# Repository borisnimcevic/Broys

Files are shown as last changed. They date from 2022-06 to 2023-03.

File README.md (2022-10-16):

# Watchular (ESP32-C3 based modular watch)

### Name origin:
* watch + modular

### Bill Of Materials
|Component  |Quantity |Link |
|----- |----- |-----  |
|ESP32-C3 |1 |[digikey](https://www.digikey.se/en/products/detail/espressif-systems/ESP32-C3-MINI-1-N4-A/15817506) |
|or with embedded flash (ESP32-C3FN4) |1 |[digikey](https://www.digikey.se/en/products/detail/espressif-systems/ESP32-C3FH4/14115592) |
|Battery charger|1 |[digikey](https://www.digikey.se/en/products/detail/microchip-technology/MCP73832T-2DCI-OT/1223150) |
|Battery connector|1 |[digikey](https://www.digikey.se/en/products/detail/w%C3%BCrth-elektronik/665102131822/5047757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) |
|Button|2 |[digikey](https://www.digikey.se/en/products/detail/e-switch/TL3301AF260QG/378995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) |
|Ceramic antenna (chip antenna)|1 |[digikey](https://www.digikey.se/en/products/detail/johanson-technology-inc/2450AT18A100E/1560676) |
|Ceramic capacitor 100nF 0402 |4 |[digikey](https://www.digikey.se/en/products/detail/taiyo-yuden/EMK105B7104KV-F/1004039) |
|Ceramic capacitor 1pF 0402 |1 |[digikey](https://www.digikey.se/en/products/detail/walsin-technology-corporation/0402N1R0B500CT/9354767) |
|Ceramic capacitor 1uF 0603 |2 |[digikey](https://www.digikey.se/en/products/detail/taiyo-yuden/EMK107BJ105KA-T/930603) |
|Ceramic capacitor 2.2uF 0603 |2 |[digikey](https://www.digikey.se/en/products/detail/taiyo-yuden/EMK107BJ225KA-T/1004018) |
|Ceramic capacitor 4.7uF 0402 |1 |[digikey](https://www.digikey.se/en/products/detail/murata-electronics/GRT155R60J475ME13J/13904800) |
|Ceramic capacitor 4.7uF 0603 |2 |[digikey](https://www.digikey.se/en/products/detail/taiyo-yuden/JMK107BJ475KA-T/1169922) |
|Ceramic capacitor 8pF 0402 |2 |[digikey](https://www.digikey.se/en/products/detail/taiyo-yuden/UMK105CH080DVHF/6563655) |
|Ceramic inductor 2.7nH |1 |[digikey](https://www.digikey.se/en/products/detail/johanson-technology-inc/L-07C2N7SV6T/1830166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) |
|Ceramic inductor 3.9nH |1 |[digikey](https://www.digikey.se/en/products/detail/johanson-technology-inc/L-07C3N9SV6T/1915227) |
|Crystal 16MHz|1 |[digikey](https://www.digikey.se/en/products/detail/txc-corporation/8Y-16-000MAHQ-T/6130681) |
|FLASH 4MBIT |1 |[digikey](https://www.digikey.se/en/products/detail/winbond-electronics/W25Q16JVSSIM/12143335) |
|LDO 3.3V 600mA|1 |[digikey](https://www.digikey.se/en/products/detail/diodes-incorporated/AP7366-33W5-7/9867322) |
|LED Orange 0402|1 |[digikey](https://www.digikey.se/en/products/detail/sunled/XZMOK68W-2/4902071) |
|LED Red 0603|30 |[digikey](https://www.digikey.se/en/products/detail/liteon/LTST-C191KRKT/386837) |
|Male Header 16 positions (1 row)|2 |[digikey](https://www.digikey.se/en/products/detail/adam-tech/PH1-16-UA/9830344) |
|N-channel MOSFET|4 |[digikey](https://www.digikey.se/en/products/detail/toshiba-semiconductor-and-storage/T2N7002AK-LM/5298028) |
|P-channel MOSFET|1 |[digikey](https://www.digikey.se/en/products/detail/diodes-incorporated/DMP2004K-7/1774201) |
|Resistor 0 ohm 0402 |1 |[digikey](https://www.digikey.se/en/products/detail/yageo/RC0402JR-070RP/4935294) |
|Resistor 100k 0402 |1 |[digikey](https://www.digikey.se/en/products/detail/yageo/RC0402JR-07100KL/726416) |
|Resistor 10k 0402 |4 |[digikey](https://www.digikey.se/en/products/detail/yageo/RC0402JR-0710KL/726418) |
|Resistor 1k 0402 |5 |[digikey](https://www.digikey.se/en/products/detail/delta-electronics-cyntec/PFR05S-102-JNH/9761533) |
|Resistor 2k 0402 |1 |[digikey](https://www.digikey.se/en/products/detail/yageo/RC0402JR-072KL/726434) |
|Resistor 5.1k 1% 0402 |2 |[digikey](https://www.digikey.se/en/products/detail/yageo/RC0402FR-135K1L/14286364) |
|Resistor 560 0402 |9 |[digikey](https://www.digikey.se/en/products/detail/yageo/RC0402JR-07560RL/726492) |
|Schottky|1 |[digikey](https://www.digikey.se/en/products/detail/smc-diode-solutions/DSS16U/8341861) |
|USB-C|1 |[digikey](https://www.digikey.se/en/products/detail/gct/USB4105-GF-A/11198441) |
|ESD-protector|1 |[digikey](https://www.digikey.se/en/products/detail/smc-diode-solutions/SR05/10820120) |

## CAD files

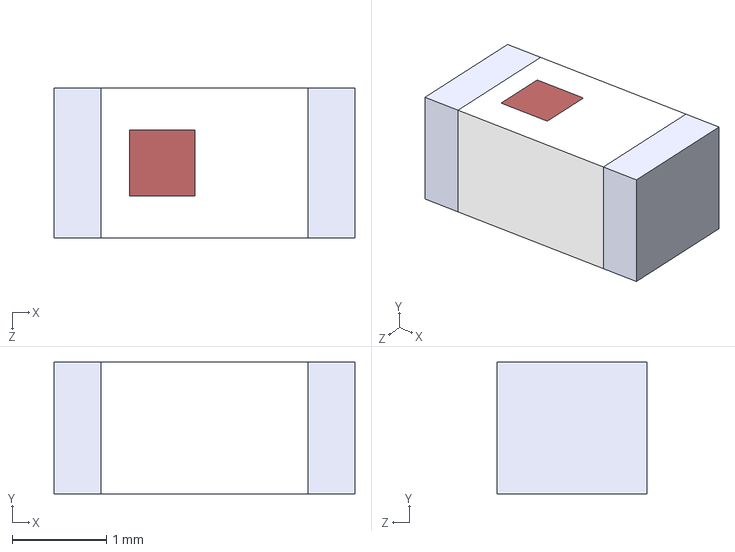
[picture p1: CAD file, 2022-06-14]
hardware/kicad-parts/ANT-2450AT18A100E/2450AT18A100E.step
3.20 x 1.40 x 1.60 mm

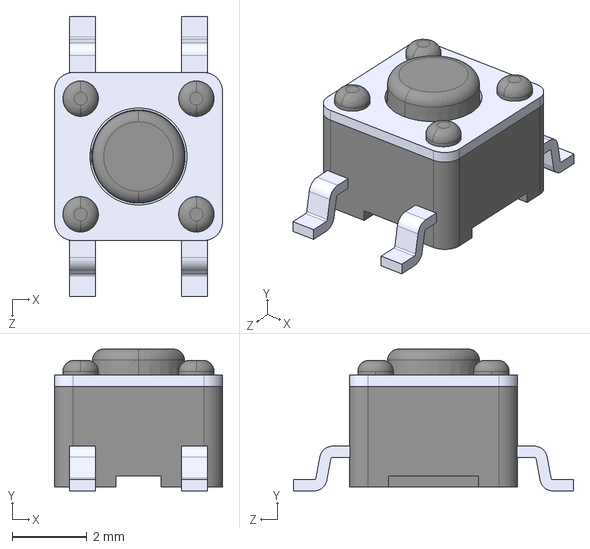
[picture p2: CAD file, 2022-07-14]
hardware/kicad-parts/button_TL3305AF260QG/TL3305AF260QG.step
4.50 x 3.80 x 7.50 mm

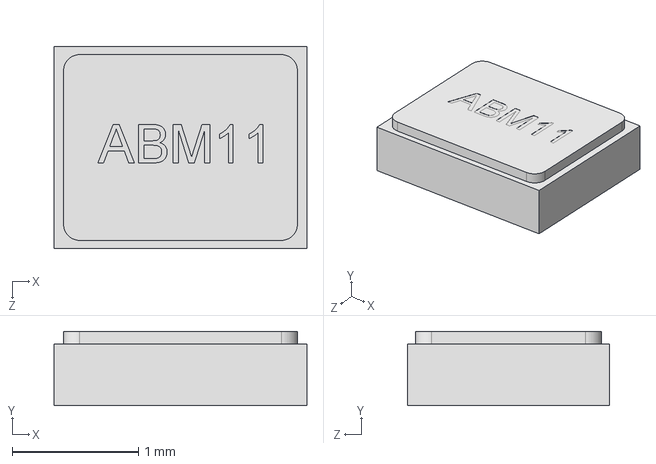
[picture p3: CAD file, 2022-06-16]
hardware/kicad-parts/Crystal/ABM1116.000MHZ-B7GT.STEP
2.01 x 0.59 x 1.60 mm

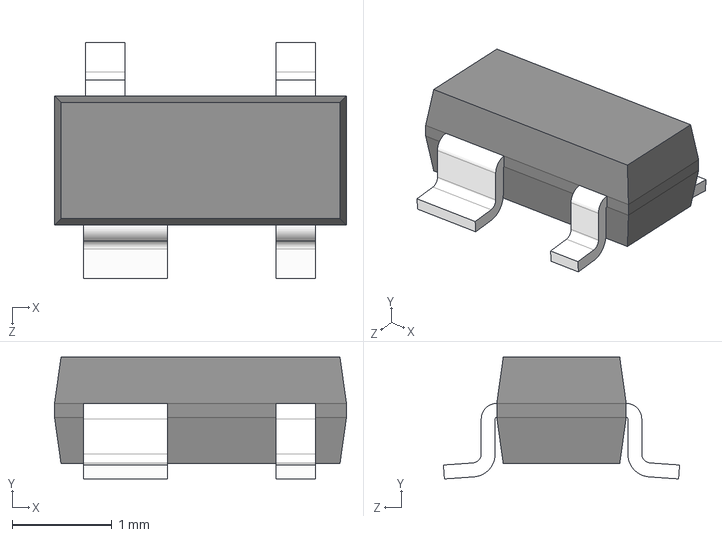
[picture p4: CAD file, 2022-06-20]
hardware/kicad-parts/ESD_protection-SR05/SR05.step
2.92 x 1.22 x 2.36 mm

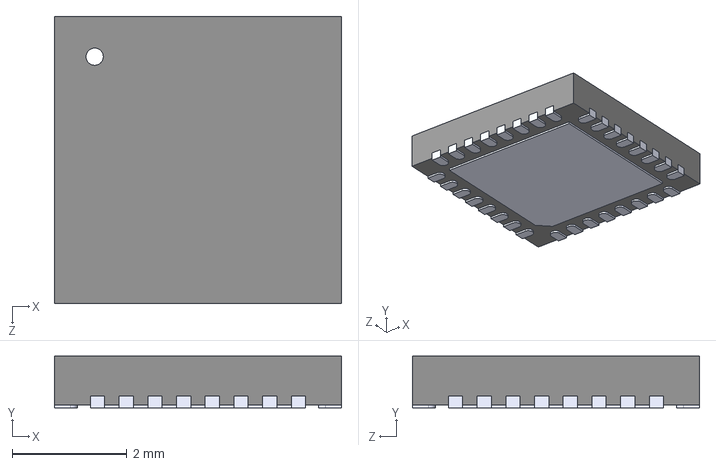
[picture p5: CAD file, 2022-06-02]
hardware/kicad-parts/ESP32-C3/ESP32-C3FH4.step
5.00 x 0.9 x 5.00 mm

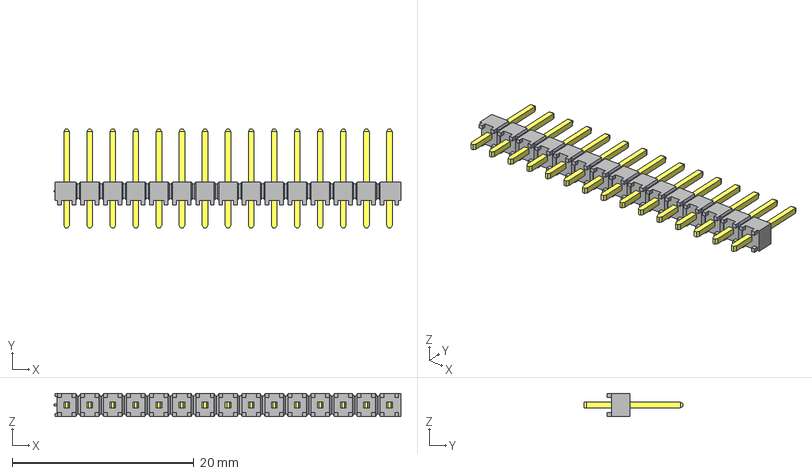
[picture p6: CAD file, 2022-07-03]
hardware/kicad-parts/header-TSW-115-07-H-S/TSW-115-07-H-S.step
38.2 x 10.9 x 2.54 mm
T-1S6-07-TSW-1-07-15-S
TSW-115-07-H-S_body

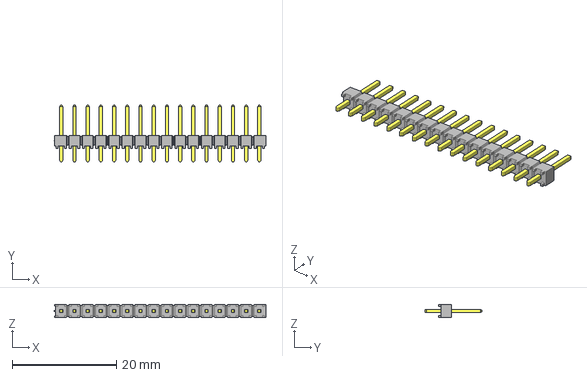
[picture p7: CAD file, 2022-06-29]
hardware/kicad-parts/header-TSW-116-07-H-S/TSW-116-07-H-S.step
40.8 x 10.9 x 2.54 mm
T-1S6-07-TSW-1-07-16-S
TSW-116-07-H-S_body

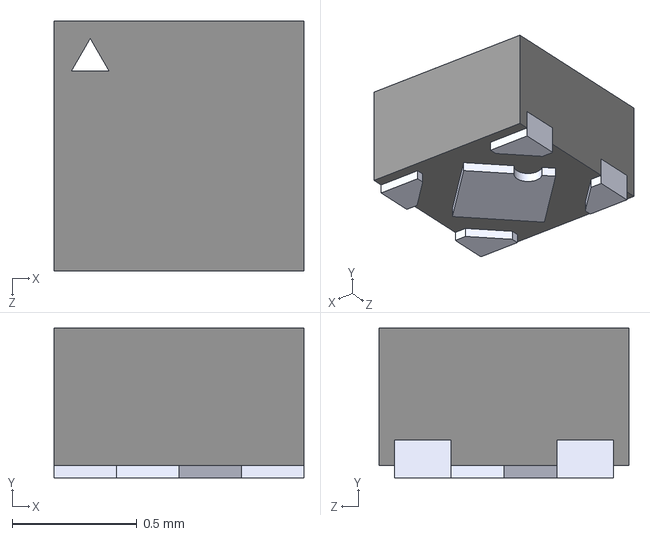
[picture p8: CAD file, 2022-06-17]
hardware/kicad-parts/LDO-MIC5524-3-3YMT-TZ/MIC5524-3.3YMT-TZ.step
1.00 x 0.6 x 1.00 mm

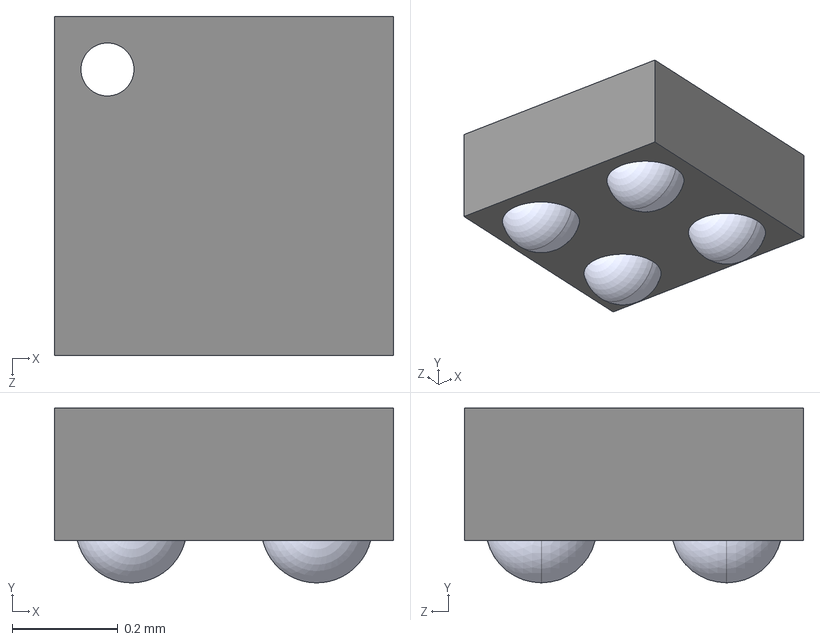
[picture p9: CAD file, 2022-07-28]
hardware/kicad-parts/LDO-NCP161AFCT330T2G/NCP161BFCT330T2G.step
0.64 x 0.33 x 0.64 mm

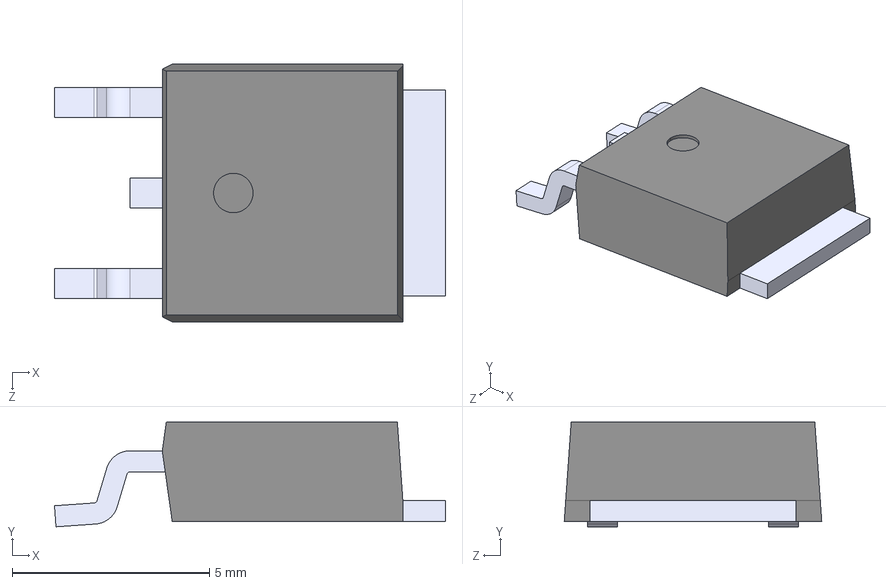
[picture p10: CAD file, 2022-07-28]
hardware/kicad-parts/LDO-UA78M33CKVURG3/UA78M33CKVURG3.step
9.90 x 2.65 x 6.52 mm

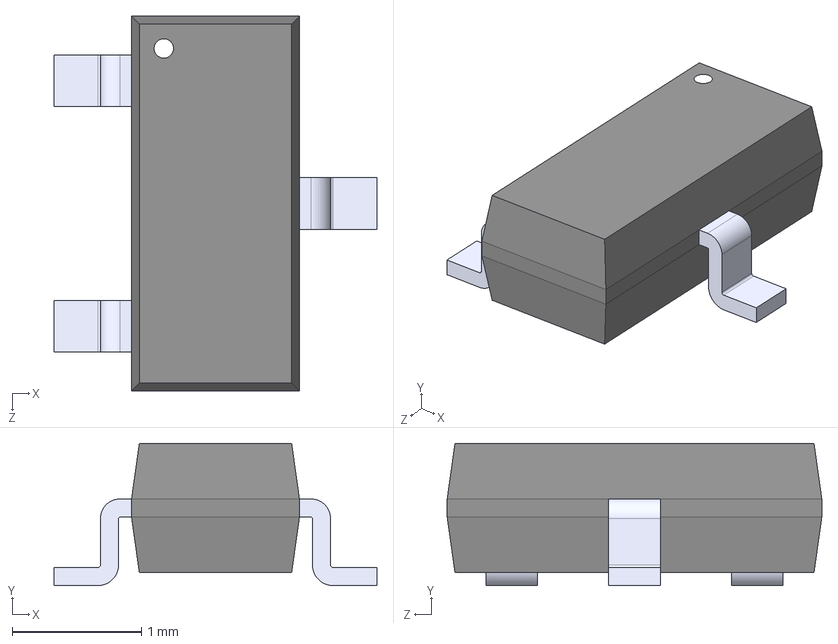
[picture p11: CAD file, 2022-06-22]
hardware/kicad-parts/MOSFET-BSS123/BSS123.step
2.50 x 1.10 x 2.90 mm

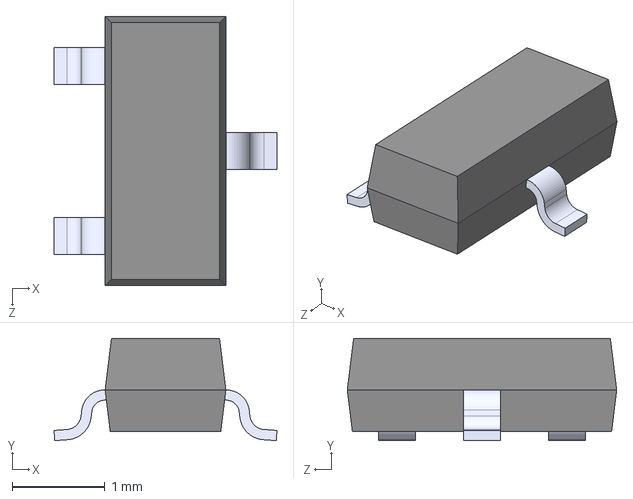
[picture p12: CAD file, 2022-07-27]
hardware/kicad-parts/N_MOSFET_STO91P240X105/SOT91P240X105-3N.step
2.40 x 1.10 x 2.90 mm

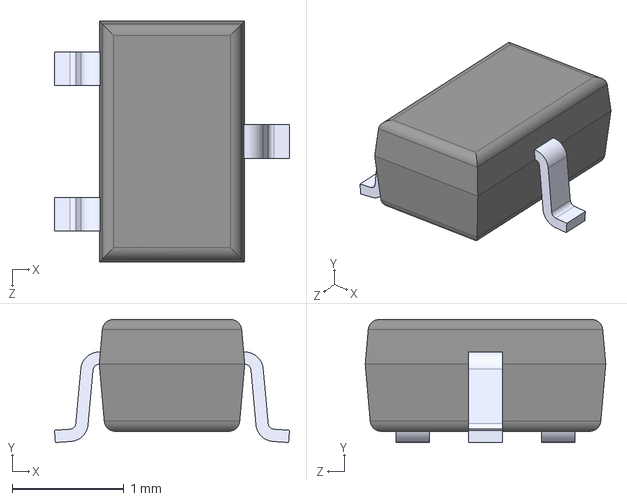
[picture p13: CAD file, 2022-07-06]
hardware/kicad-parts/P_MOSFET-DMG1013UW/DMG1013UW-7.step
2.10 x 1.10 x 2.15 mm

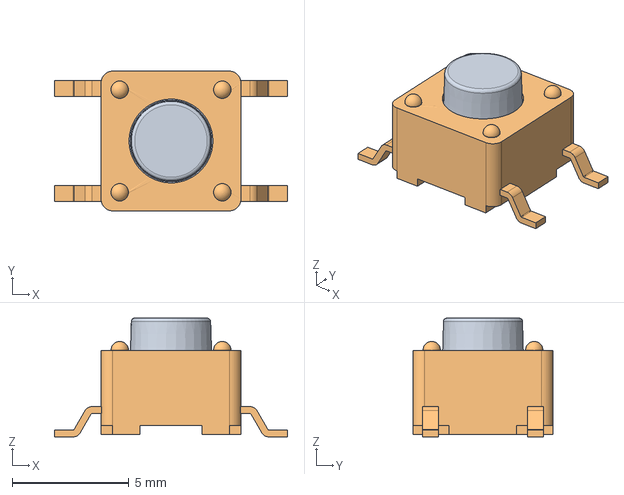
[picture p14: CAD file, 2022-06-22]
hardware/kicad-parts/switch-TL3301AF260QG/TL3301AF260QG.step
10.0 x 6.00 x 5.10 mm

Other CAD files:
hardware/kicad-parts/USBC-USB4105-GF-A/USB4105-GF-A.step
hardware/kicad-parts/battery_charger-MCP73832T/MCP73832T-2DCI_OT.step
hardware/kicad-parts/battery_connector-665102131822/665102131822.step

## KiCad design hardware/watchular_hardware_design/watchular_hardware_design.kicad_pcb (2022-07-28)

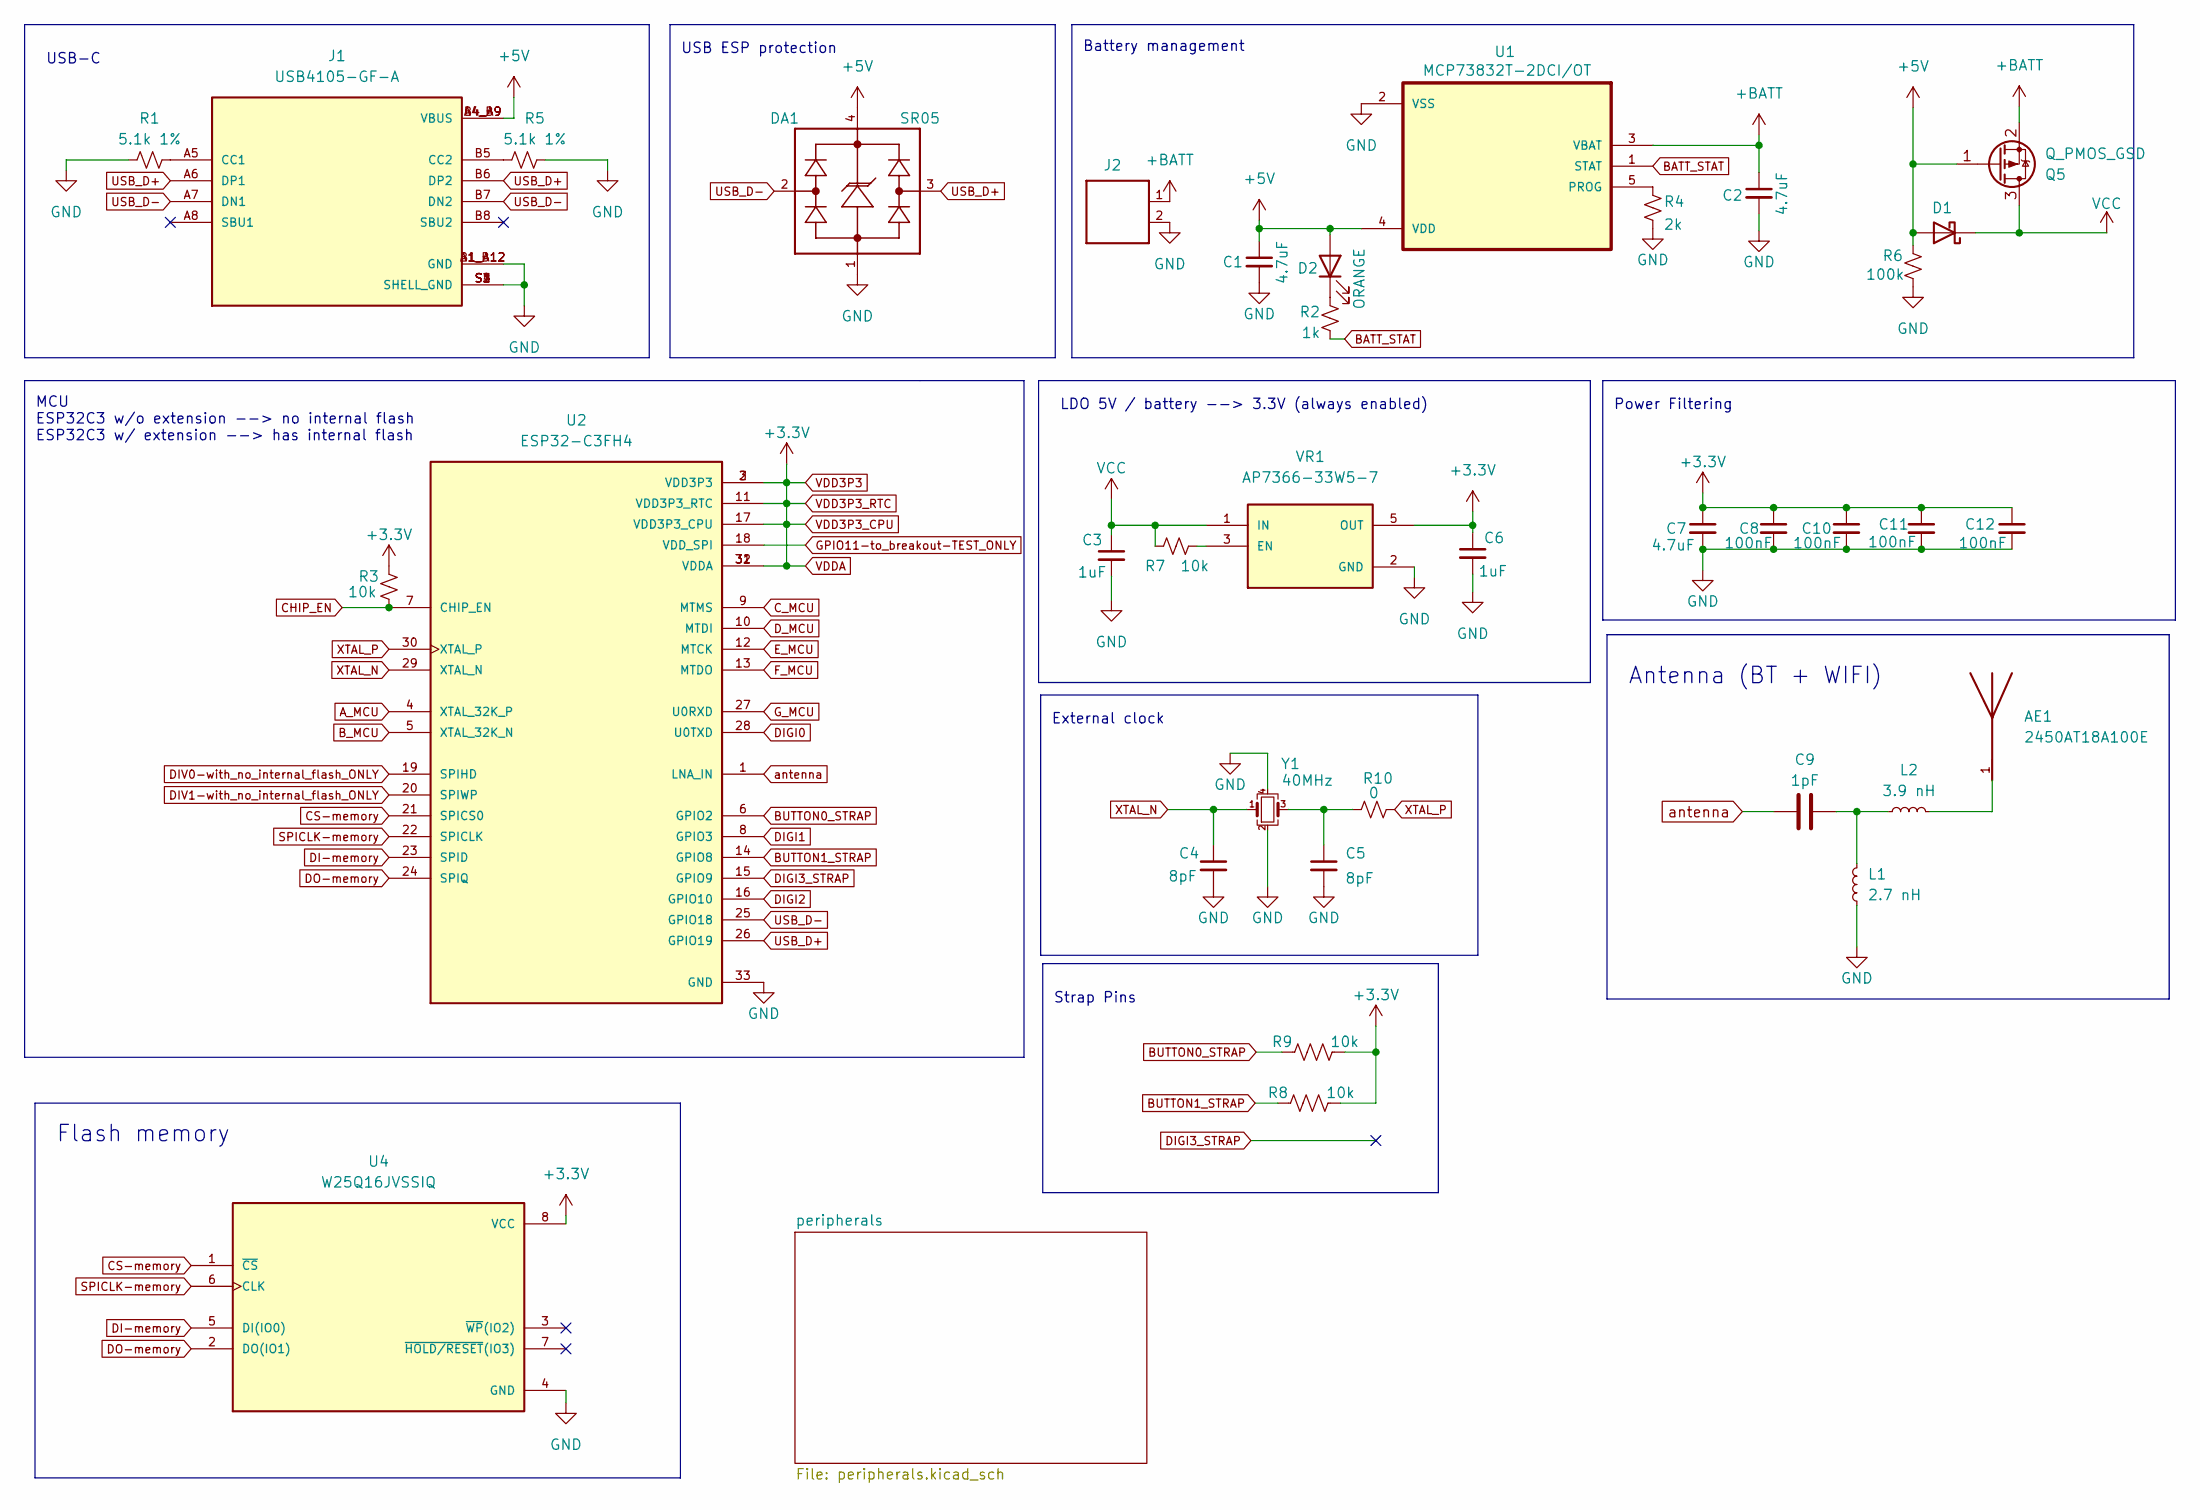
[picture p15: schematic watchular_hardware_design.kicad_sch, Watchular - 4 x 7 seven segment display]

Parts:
AE1: 2450AT18A100E; ANTC3216X140N; PARTREV 1.3
C1, C2: 4.7uF; C_0603_1608Metric_Pad1.08x0.95mm_HandSolder
C3, C6: 1uF; C_0603_1608Metric_Pad1.08x0.95mm_HandSolder
C4, C5: 8pF; C_0402_1005Metric_Pad0.74x0.62mm_HandSolder
C7: 4.7uF; L_0402_1005Metric
C8, C10, C11, C12: 100nF; L_0402_1005Metric
C9: 1pF; C_0402_1005Metric
D1: D_Schottky; D_SOD-123F
D2: ORANGE; LED_0402_1005Metric_Pad0.77x0.64mm_HandSolder
DA1: SR05; SOT143
J1: USB4105-GF-A; GCT_USB4105-GF-A; PARTREV A3
J2: 665102131822
L1: 2.7 nH; L_0402_1005Metric
L2: 3.9 nH; L_0402_1005Metric
Q5: Q_PMOS_GSD; SOT91P240X105-3N
R1, R5: 5.1k 1%; R_0402_1005Metric_Pad0.72x0.64mm_HandSolder
R2: 1k; R_0402_1005Metric_Pad0.72x0.64mm_HandSolder
R3, R7, R8, R9: 10k; R_0402_1005Metric_Pad0.72x0.64mm_HandSolder
R4: 2k; R_0402_1005Metric_Pad0.72x0.64mm_HandSolder
R6: 100k; R_0402_1005Metric_Pad0.72x0.64mm_HandSolder
R10: 0; R_0402_1005Metric_Pad0.72x0.64mm_HandSolder
U1: MCP73832T-2DCI/OT; SOT95P280X145-5N
U2: ESP32-C3FH4; QFN50P500X500X90-33N; PARTREV V1.0
U4: W25Q16JVSSIQ; SOIC127P790X216-8N
VR1: AP7366-33W5-7; SOT95P285X140-5N; PARTREV 1-2
Y1: 40MHz; Crystal_SMD_2016-4Pin_2.0x1.6mm

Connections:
+5V: C1.1, D1.2 (A), D2.2 (A), DA1.4, J1.A4_B9 (VBUS), J1.B4_A9 (VBUS), Q5.1 (G), R6.1, U1.4 (VDD); also elsewhere on the board
+BATT: C2.1, J2.1, Q5.2 (S), U1.3 (VBAT); also elsewhere on the board
A_MCU: U2.4 (XTAL_32K_P); also elsewhere on the board
BATT_STAT: R2.2, U1.1 (STAT)
BUTTON0_STRAP: R9.1, U2.6 (GPIO2); also elsewhere on the board
BUTTON1_STRAP: R8.1, U2.14 (GPIO8); also elsewhere on the board
B_MCU: U2.5 (XTAL_32K_N); also elsewhere on the board
CHIP_EN: R3.2, U2.7 (CHIP_EN); also elsewhere on the board
CS-memory: U2.21 (SPICS0), U4.1 (~CS); also elsewhere on the board
C_MCU: U2.9 (MTMS); also elsewhere on the board
DI-memory: U2.23 (SPID), U4.5 (DI(IO0)); also elsewhere on the board
DIGI0: U2.28 (U0TXD); also elsewhere on the board
DIGI1: U2.8 (GPIO3); also elsewhere on the board
DIGI2: U2.16 (GPIO10); also elsewhere on the board
DIGI3_STRAP: U2.15 (GPIO9); also elsewhere on the board
DIV0-with_no_internal_flash_ONLY: U2.19 (SPIHD); also elsewhere on the board
DIV1-with_no_internal_flash_ONLY: U2.20 (SPIWP); also elsewhere on the board
DO-memory: U2.24 (SPIQ), U4.2 (DO(IO1)); also elsewhere on the board
D_MCU: U2.10 (MTDI); also elsewhere on the board
E_MCU: U2.12 (MTCK); also elsewhere on the board
F_MCU: U2.13 (MTDO); also elsewhere on the board
GND: C1.2, C2.2, C3.2, C4.2, C5.2, C6.2, C7.2, C8.2, C10.2, C11.2, C12.2, DA1.1, J1.A1_B12 (GND), J1.B1_A12 (GND), J1.S1 (SHELL_GND), J1.S2 (SHELL_GND), J1.S3 (SHELL_GND), J1.S4 (SHELL_GND), J2.2, L1.1, R1.1, R4.2, R5.2, R6.2, U1.2 (VSS), U2.33 (GND), U4.4 (GND), VR1.2 (GND), Y1.2, Y1.4; also elsewhere on the board
GPIO11-to_breakout-TEST_ONLY: U2.18 (VDD_SPI); also elsewhere on the board
G_MCU: U2.27 (U0RXD); also elsewhere on the board
unnamed: AE1.1, L2.2
unnamed: C5.1, R10.1, Y1.3
unnamed: C9.2, L1.2, L2.1
unnamed: D2.1 (K), R2.1
unnamed: J1.A5 (CC1), R1.2
unnamed: J1.B5 (CC2), R5.1
unnamed: R4.1, U1.5 (PROG)
unnamed: R7.2, VR1.3 (EN)
SPICLK-memory: U2.22 (SPICLK), U4.6 (CLK); also elsewhere on the board
USB_D+: DA1.3, J1.A6 (DP1), J1.B6 (DP2), U2.26 (GPIO19); also elsewhere on the board
USB_D-: DA1.2, J1.A7 (DN1), J1.B7 (DN2), U2.25 (GPIO18); also elsewhere on the board
VCC: C3.1, D1.1 (K), Q5.3 (D), R7.1, VR1.1 (IN)
VDD3P3: C6.1, C7.1, C8.1, C10.1, C11.1, C12.1, R3.1, R8.2, R9.2, U2.2 (VDD3P3), U2.3 (VDD3P3), U2.11 (VDD3P3_RTC), U2.17 (VDD3P3_CPU), U2.31 (VDDA), U2.32 (VDDA), U4.8 (VCC), VR1.5 (OUT); also elsewhere on the board
XTAL_N: C4.1, U2.29 (XTAL_N), Y1.1; also elsewhere on the board
XTAL_P: R10.2, U2.30 (XTAL_P); also elsewhere on the board
antenna: C9.1, U2.1 (LNA_IN)

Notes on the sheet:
USB-C
LDO 5V / battery --> 3.3V (always enabled)
Battery management
Flash memory
Power Filtering
Antenna (BT + WIFI)
External clock
MCU ESP32C3 w/o extension --> no internal flash ESP32C3 w/ extension --> has internal flash
Strap Pins
USB ESP protection

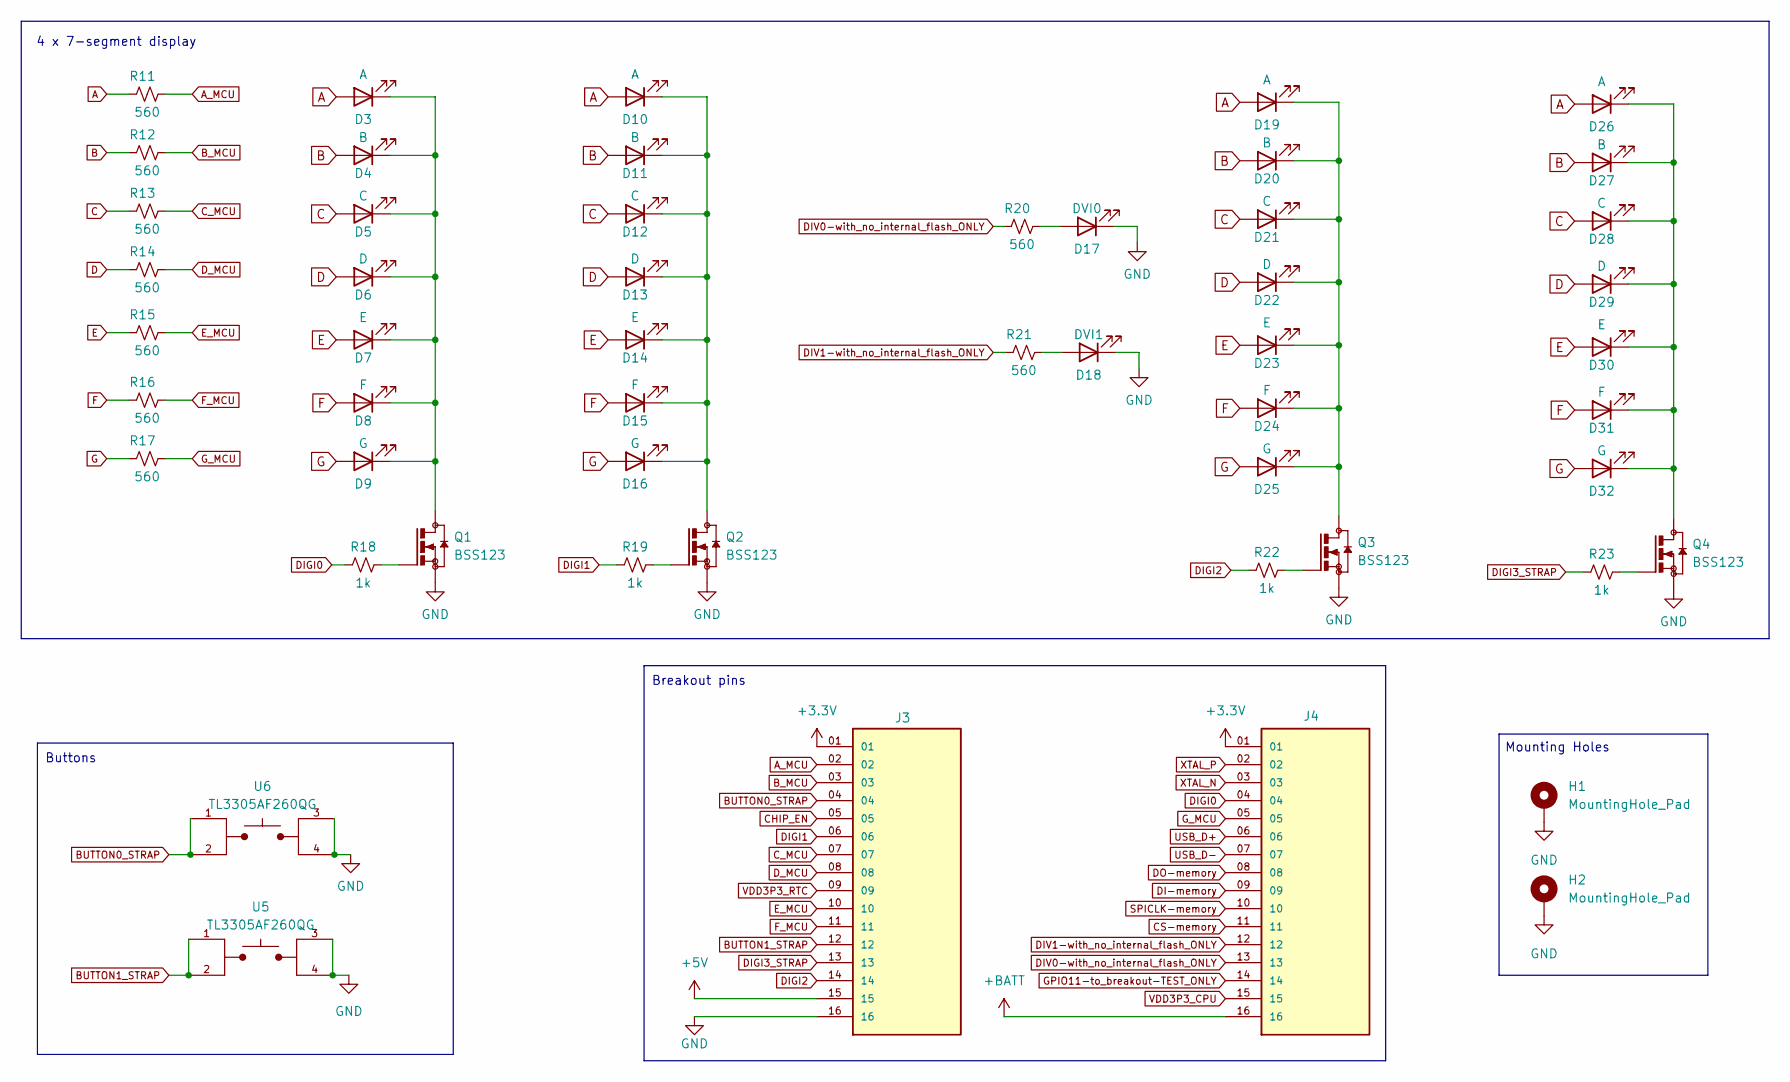
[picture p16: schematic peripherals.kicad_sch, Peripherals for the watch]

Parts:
D3, D10, D19, D26: A; LED_0603_custom_boris
D4, D11, D20, D27: B; LED_0603_custom_boris
D5, D12, D21, D28: C; LED_0603_custom_boris
D6, D13, D22, D29: D; LED_0603_custom_boris
D7, D14, D23, D30: E; LED_0603_custom_boris
D8, D15, D24, D31: F; LED_0603_custom_boris
D9, D16, D25, D32: G; LED_0603_custom_boris
D17: DVI0; LED_0603_custom_boris
D18: DVI1; LED_0603_custom_boris
H1, H2: MountingHole_Pad; MountingHole_2.2mm_M2_Pad_Via
J3, J4: TSW-116-07-H-S; SAMTEC_TSW-116-07-H-S; PARTREV R
Q1, Q2, Q3, Q4: BSS123; SOT23
R11, R12, R13, R14, R15, R16, R17, R20, R21: 560; R_0402_1005Metric_Pad0.72x0.64mm_HandSolder
R18, R19, R22, R23: 1k; R_0402_1005Metric_Pad0.72x0.64mm_HandSolder
U5, U6: TL3305AF260QG; SW_TL3305AF260QG; PARTREV C

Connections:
+5V: J3.15; also elsewhere on the board
+BATT: J4.16; also elsewhere on the board
A: D3.2 (A), D10.2 (A), D19.2 (A), D26.2 (A), R11.1
A_MCU: J3.02, R11.2; also elsewhere on the board
B: D4.2 (A), D11.2 (A), D20.2 (A), D27.2 (A), R12.1
BUTTON0_STRAP: J3.04, U6.1, U6.2; also elsewhere on the board
BUTTON1_STRAP: J3.12, U5.1, U5.2; also elsewhere on the board
B_MCU: J3.03, R12.2; also elsewhere on the board
C: D5.2 (A), D12.2 (A), D21.2 (A), D28.2 (A), R13.1
CHIP_EN: J3.05; also elsewhere on the board
CS-memory: J4.11; also elsewhere on the board
C_MCU: J3.07, R13.2; also elsewhere on the board
D: D6.2 (A), D13.2 (A), D22.2 (A), D29.2 (A), R14.1
DI-memory: J4.09; also elsewhere on the board
DIGI0: J4.04, R18.1; also elsewhere on the board
DIGI1: J3.06, R19.1; also elsewhere on the board
DIGI2: J3.14, R22.1; also elsewhere on the board
DIGI3_STRAP: J3.13, R23.1; also elsewhere on the board
DIV0-with_no_internal_flash_ONLY: J4.13, R20.1; also elsewhere on the board
DIV1-with_no_internal_flash_ONLY: J4.12, R21.1; also elsewhere on the board
DO-memory: J4.08; also elsewhere on the board
D_MCU: J3.08, R14.2; also elsewhere on the board
E: D7.2 (A), D14.2 (A), D23.2 (A), D30.2 (A), R15.1
E_MCU: J3.10, R15.2; also elsewhere on the board
F: D8.2 (A), D15.2 (A), D24.2 (A), D31.2 (A), R16.1
F_MCU: J3.11, R16.2; also elsewhere on the board
G: D9.2 (A), D16.2 (A), D25.2 (A), D32.2 (A), R17.1
GND: D17.1 (K), D18.1 (K), H1.1, H2.1, J3.16, Q1.2, Q2.2, Q3.2, Q4.2, U5.3, U5.4, U6.3, U6.4; also elsewhere on the board
GPIO11-to_breakout-TEST_ONLY: J4.14; also elsewhere on the board
G_MCU: J4.05, R17.2; also elsewhere on the board
unnamed: D3.1 (K), D4.1 (K), D5.1 (K), D6.1 (K), D7.1 (K), D8.1 (K), D9.1 (K), Q1.3
unnamed: D10.1 (K), D11.1 (K), D12.1 (K), D13.1 (K), D14.1 (K), D15.1 (K), D16.1 (K), Q2.3
unnamed: D17.2 (A), R20.2
unnamed: D18.2 (A), R21.2
unnamed: D19.1 (K), D20.1 (K), D21.1 (K), D22.1 (K), D23.1 (K), D24.1 (K), D25.1 (K), Q3.3
unnamed: D26.1 (K), D27.1 (K), D28.1 (K), D29.1 (K), D30.1 (K), D31.1 (K), D32.1 (K), Q4.3
unnamed: Q1.1, R18.2
unnamed: Q2.1, R19.2
unnamed: Q3.1, R22.2
unnamed: Q4.1, R23.2
SPICLK-memory: J4.10; also elsewhere on the board
USB_D+: J4.06; also elsewhere on the board
USB_D-: J4.07; also elsewhere on the board
VDD3P3: J3.01, J3.09, J4.01, J4.15; also elsewhere on the board
XTAL_N: J4.03; also elsewhere on the board
XTAL_P: J4.02; also elsewhere on the board

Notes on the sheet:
Breakout pins
4 x 7-segment display
Buttons
Mounting Holes

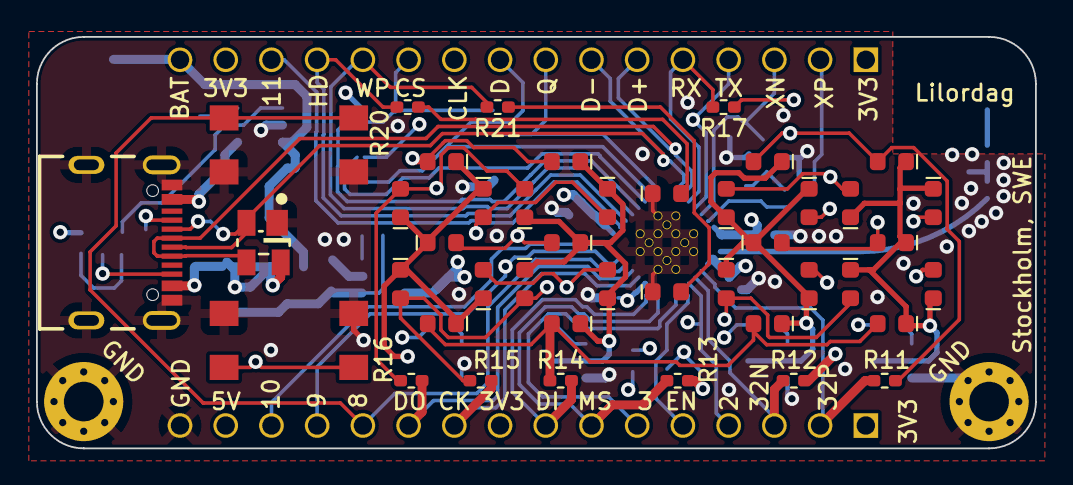
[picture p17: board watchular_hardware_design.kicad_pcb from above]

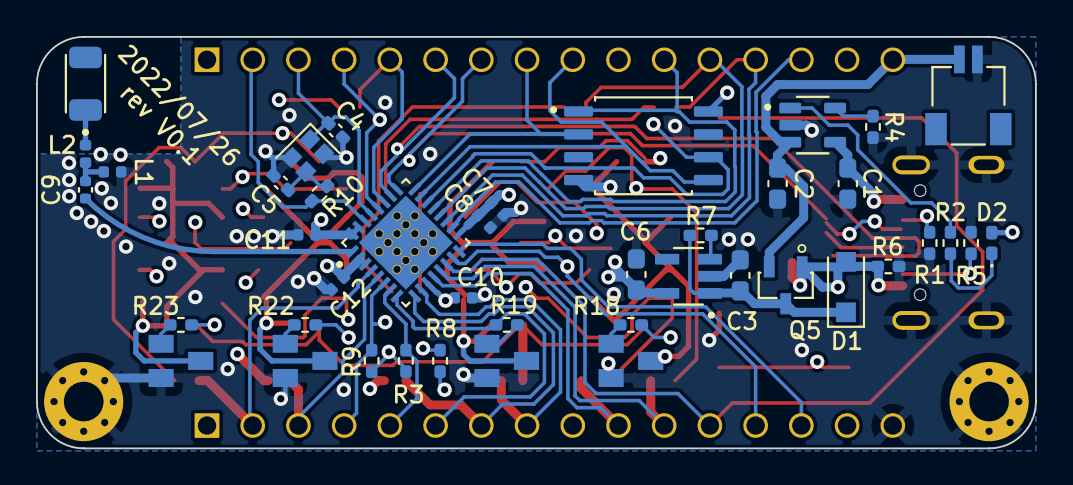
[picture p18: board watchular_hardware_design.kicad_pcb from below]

Board: 4 copper layers, 55.5 x 22.9 mm, 89 parts (42 on the bottom side), 57 nets.

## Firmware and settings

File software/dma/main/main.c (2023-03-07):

#include "esp_attr.h"
#include "esp_event.h"
#include "esp_log.h"
#include "esp_timer.h"
#include "esp_wifi.h"
#include "esp_wifi_types.h"
#include "freertos/FreeRTOS.h"
#include "freertos/event_groups.h"
#include "freertos/task.h"
#include "nvs_flash.h"
#include "pin_config.h"
#include "secret_file.h"

#define TAG "Boris"

#define TIMER_DISPALY_REFRESH_US 5000   // micro seconds
#define TIMER_COUNTER_INCREMENT_MS 6000 // mili seconds

#define PLACE_MASK 0x03

#define MAXIMUM_WIFI_RETRY 5

#define WIFI_CONNECTED_BIT BIT0
#define WIFI_FAIL_BIT BIT1

#if CONFIG_ESP_WIFI_AUTH_OPEN
#define ESP_WIFI_SCAN_AUTH_MODE_THRESHOLD WIFI_AUTH_OPEN
#elif CONFIG_ESP_WIFI_AUTH_WEP
#define ESP_WIFI_SCAN_AUTH_MODE_THRESHOLD WIFI_AUTH_WEP
#elif CONFIG_ESP_WIFI_AUTH_WPA_PSK
#define ESP_WIFI_SCAN_AUTH_MODE_THRESHOLD WIFI_AUTH_WPA_PSK
#elif CONFIG_ESP_WIFI_AUTH_WPA2_PSK
#define ESP_WIFI_SCAN_AUTH_MODE_THRESHOLD WIFI_AUTH_WPA2_PSK
#elif CONFIG_ESP_WIFI_AUTH_WPA_WPA2_PSK
#define ESP_WIFI_SCAN_AUTH_MODE_THRESHOLD WIFI_AUTH_WPA_WPA2_PSK
#elif CONFIG_ESP_WIFI_AUTH_WPA3_PSK
#define ESP_WIFI_SCAN_AUTH_MODE_THRESHOLD WIFI_AUTH_WPA3_PSK
#elif CONFIG_ESP_WIFI_AUTH_WPA2_WPA3_PSK
#define ESP_WIFI_SCAN_AUTH_MODE_THRESHOLD WIFI_AUTH_WPA2_WPA3_PSK
#elif CONFIG_ESP_WIFI_AUTH_WAPI_PSK
#define ESP_WIFI_SCAN_AUTH_MODE_THRESHOLD WIFI_AUTH_WAPI_PSK
#endif

static uint8_t number[4] = {0};

/* FreeRTOS event group to signal when we are connected*/
static EventGroupHandle_t s_wifi_event_group;
static int s_retry_num = 0;

void IRAM_ATTR timer_isr(void *arg) {
  static uint8_t place = 0;
  setPlace(place);
  setDigit(number[place]);
  place = (place + 1) & PLACE_MASK;
}

void counter_task(void *arg) {
  uint32_t counter = 0;
  while (1) {
    counter++;
    uint32_t temp = counter;
    for (int i = 3; i >= 0; i--) {
      number[i] = temp % 10;
      temp /= 10;
    }
    vTaskDelay(pdMS_TO_TICKS(TIMER_COUNTER_INCREMENT_MS));
    printf("counter = %d\n", counter);
  }
}

void time_task(void *arg) {

}
static void event_handler(void *arg, esp_event_base_t event_base,
                          int32_t event_id, void *event_data) {
  if (event_base == WIFI_EVENT && event_id == WIFI_EVENT_STA_START) {
    esp_wifi_connect();
  } else if (event_base == WIFI_EVENT &&
             event_id == WIFI_EVENT_STA_DISCONNECTED) {
    if (s_retry_num < MAXIMUM_WIFI_RETRY) {
      esp_wifi_connect();
      s_retry_num++;
      ESP_LOGI(TAG, "retry to connect to the AP, try no.: %d", s_retry_num);
    } else {
      xEventGroupSetBits(s_wifi_event_group, WIFI_FAIL_BIT);
    }
  } else if (event_base == IP_EVENT && event_id == IP_EVENT_STA_GOT_IP) {
    ip_event_got_ip_t *event = (ip_event_got_ip_t *)event_data;
    ESP_LOGI(TAG, "got ip: " IPSTR, IP2STR(&event->ip_info.ip));
    s_retry_num = 0;
    xEventGroupSetBits(s_wifi_event_group, WIFI_CONNECTED_BIT);
  }
}

void setupWifi(void) {
  // Initialize NVS
  esp_err_t ret = nvs_flash_init();
  if (ret == ESP_ERR_NVS_NO_FREE_PAGES ||
      ret == ESP_ERR_NVS_NEW_VERSION_FOUND) {
    ESP_ERROR_CHECK(nvs_flash_erase());
    ret = nvs_flash_init();
  }
  ESP_ERROR_CHECK(ret);

  ESP_LOGI(TAG, "ESP_WIFI_MODE_STA");
  // setup wifi

  s_wifi_event_group = xEventGroupCreate();
  ESP_ERROR_CHECK(esp_netif_init());
  ESP_ERROR_CHECK(esp_event_loop_create_default());
  esp_netif_create_default_wifi_sta();

  wifi_init_config_t cfg = WIFI_INIT_CONFIG_DEFAULT();
  ESP_ERROR_CHECK(esp_wifi_init(&cfg));

  esp_event_handler_instance_t instance_any_id;
  esp_event_handler_instance_t instance_got_ip;
  ESP_ERROR_CHECK(esp_event_handler_instance_register(
      WIFI_EVENT, ESP_EVENT_ANY_ID, &event_handler, NULL, &instance_any_id));
  ESP_ERROR_CHECK(esp_event_handler_instance_register(
      IP_EVENT, IP_EVENT_STA_GOT_IP, &event_handler, NULL, &instance_got_ip));

  wifi_config_t wifi_config = {
      .sta =
          {
              .ssid = MY_SSID, .password = MY_PASSWORD,
              /* Setting a password implies station will connect to all security
               * modes including WEP/WPA. However these modes are deprecated and
               * not advisable to be used. Incase your Access point doesn't
               * support WPA2, these mode can be enabled by commenting below
               * line */
              // .threshold.authmode = ESP_WIFI_SCAN_AUTH_MODE_THRESHOLD,
              // .threshold.authmode = WIFI_AUTH_OPEN,
              // .sae_pwe_h2e = WPA3_SAE_PWE_BOTH,
          },
  };

  ESP_LOGI(TAG, "config setup");

  ESP_ERROR_CHECK(esp_wifi_set_mode(WIFI_MODE_STA));
  ESP_ERROR_CHECK(esp_wifi_set_config(WIFI_IF_STA, &wifi_config));
  ESP_ERROR_CHECK(esp_wifi_start());

  ESP_LOGI(TAG, "wifi_init_sta finished.");

  /* Waiting until either the connection is established (WIFI_CONNECTED_BIT) or
   * connection failed for the maximum number of re-tries (WIFI_FAIL_BIT). The
   * bits are set by event_handler() (see above) */
  EventBits_t bits = xEventGroupWaitBits(s_wifi_event_group,
                                         WIFI_CONNECTED_BIT | WIFI_FAIL_BIT,
                                         pdFALSE, pdFALSE, portMAX_DELAY);

  /* xEventGroupWaitBits() returns the bits before the call returned, hence we
   * can test which event actually happened. */
  if (bits & WIFI_CONNECTED_BIT) {
    ESP_LOGI(TAG, "connected to ap SSID:%s", MY_SSID);
  } else if (bits & WIFI_FAIL_BIT) {
    ESP_LOGI(TAG, "Failed to connect to SSID:%s", MY_SSID);
  } else {
    ESP_LOGE(TAG, "UNEXPECTED EVENT");
  }
}

void app_main(void) {
  // init LEDs
  initGPIOs();
  clearLED();

  setupWifi();

  // init interupt service routine
  esp_timer_create_args_t timer_args = {.callback = timer_isr,
                                        .arg = NULL,
                                        .dispatch_method = ESP_TIMER_TASK,
                                        .name = "my_timer"};

  esp_timer_handle_t timer;
  esp_timer_create(&timer_args, &timer);
  // esp_timer_start_periodic(timer, TIMER_DISPALY_REFRESH_US);

  // create task
  // xTaskCreate(counter_task, "Counter Task", 2048, NULL, 1, NULL);
  xTaskCreate(time_task, "Time Task", 2048, NULL, 1, NULL);
  while (1) {
    vTaskDelay(1000 / portTICK_PERIOD_MS);
  }
}

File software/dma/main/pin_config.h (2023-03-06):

/*
 * Description: Pin configuration
 * Author: Boris Nimcevic
 * Date: 2023/02/03
 *
 * Copyright (C) 2023 Lilordag
 *
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
 * You should have received a copy of the GNU General Public License
 * along with this program.  If not, see <http://www.gnu.org/licenses/>.
 */

#ifndef PIN_CONFIG_H
#define PIN_CONFIG_H

#include "driver/gpio.h"

#define PIN_MAX_DIGIT 3
#define PIN_MAX_NUMBER 9

// digits (total of 4)
#define DIGI0 GPIO_NUM_21
#define DIGI1 GPIO_NUM_3
#define DIGI2 GPIO_NUM_10
#define DIGI3 GPIO_NUM_9

// parts of seven segment display
#define A_LED GPIO_NUM_0
#define B_LED GPIO_NUM_1
#define C_LED GPIO_NUM_4
#define D_LED GPIO_NUM_5
#define E_LED GPIO_NUM_6
#define F_LED GPIO_NUM_7
#define G_LED GPIO_NUM_20

static const gpio_num_t digit_pins[] = {
    // digits
    DIGI0,
    DIGI1,
    DIGI2,
    DIGI3,
};

static const gpio_num_t led_pins[] = {
    // segments
    A_LED, B_LED, C_LED, D_LED, E_LED, F_LED, G_LED,
};

static const uint8_t values[11][7] = {
    {1, 1, 1, 1, 1, 1, 0}, // 0
    {0, 1, 1, 0, 0, 0, 0}, // 1
    {1, 1, 0, 1, 1, 0, 1}, // 2
    {1, 1, 1, 1, 0, 0, 1}, // 3
    {0, 1, 1, 0, 0, 1, 1}, // 4
    {1, 0, 1, 1, 0, 1, 1}, // 5
    {1, 0, 1, 1, 1, 1, 1}, // 6
    {1, 1, 1, 0, 0, 0, 0}, // 7
    {1, 1, 1, 1, 1, 1, 1}, // 8
    {1, 1, 1, 1, 0, 1, 1}, // 9
    {0, 0, 0, 0, 0, 0, 0}, // off
};

void initGPIOs(void);
void clearLED(void);

static inline void setPlace(const uint8_t place){
  const uint8_t mask = (place <= 3) ? (1 << place) : 0;
  const uint8_t val = mask & 0x0F;
  gpio_set_level(DIGI0, val & 0x1);
  gpio_set_level(DIGI1, val & 0x2);
  gpio_set_level(DIGI2, val & 0x4);
  gpio_set_level(DIGI3, val & 0x8);
}

static inline void setDigit(const uint8_t digit) {
  const uint8_t *val = (digit <= 9) ? values[digit] : values[10];
  for (int i = 0; i < 7; i++) {
    gpio_set_level(led_pins[i], val[i]);
  }
}

#endif /* PIN_CONFIG_H */

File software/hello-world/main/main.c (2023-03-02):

#include "freertos/FreeRTOS.h"
#include "freertos/task.h"
#include "esp_log.h"

#include "pin_config.h"

// TODO: Document in readme that these can't be used
// #define DIV0 12
// #define DIV1 13
// gpio_set_direction(DIV0 , GPIO_MODE_OUTPUT);
// gpio_set_direction(DIV1, GPIO_MODE_OUTPUT);
void clearLED(void) {
  gpio_set_level(DIGI0, 0);
  gpio_set_level(DIGI1, 0);
  gpio_set_level(DIGI2, 0);
  gpio_set_level(DIGI3, 0);

  gpio_set_level(A_LED, 0);
  gpio_set_level(B_LED, 0);
  gpio_set_level(C_LED, 0);
  gpio_set_level(D_LED, 0);
  gpio_set_level(E_LED, 0);
  gpio_set_level(F_LED, 0);
  gpio_set_level(G_LED, 0);
}

TaskHandle_t led_col_task_handle;
const int delay = 4;

// void led_col_task(void *arg) {
void led_col_task(void *arg) {
  uint8_t col = 0;
  while (1) {
    // ESP_LOGI("Boris","switch -> %d", col);
    clearLED();
    // vTaskDelay(delay / portTICK_PERIOD_MS);
    switch (col) {
    case 0:
      gpio_set_level(B_LED, 1);
      gpio_set_level(C_LED, 1);
      gpio_set_level(DIGI0, 1);
      break;
    case 1:
      gpio_set_level(A_LED, 1);
      gpio_set_level(B_LED, 1);
      gpio_set_level(D_LED, 1);
      gpio_set_level(E_LED, 1);
      gpio_set_level(G_LED, 1);
      gpio_set_level(DIGI1, 1);
      break;
    case 2:
      gpio_set_level(A_LED, 1);
      gpio_set_level(B_LED, 1);
      gpio_set_level(C_LED, 1);
      gpio_set_level(D_LED, 1);
      gpio_set_level(G_LED, 1);
      gpio_set_level(DIGI2, 1);
      break;
    case 3:
      gpio_set_level(B_LED, 1);
      gpio_set_level(C_LED, 1);
      gpio_set_level(F_LED, 1);
      gpio_set_level(G_LED, 1);
      gpio_set_level(DIGI3, 1);
      break;
    default:
      break;
    }
    vTaskDelay(delay / portTICK_PERIOD_MS);
    col++;
    col %= 4;
  }
}

void app_main(void) {
  initGPIOs();

  // Create a task for each LED column
  xTaskCreate(led_col_task, "LED", 2048, NULL, 10,
              &led_col_task_handle);

  // vTaskStartScheduler();
}

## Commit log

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2022-06-02 Added external 16MBit flash
    [design-broys.kicad_pcb, design-broys.kicad_sch]
2022-06-11 Added power supplies on the esp32
    [design-broys.kicad_sch]
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2022-06-11 Added memory to the schematic.
    [design-broys.kicad_sch]
2022-06-11 Fixed the issue with kicad versioning
    [design-broys.kicad_pcb, design-broys.kicad_sch]
2022-06-12 Connected flash with the esp.
    [design-broys.kicad_sch]
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2022-06-13 Added LEDs for the first digit.
    [design-broys.kicad_pcb, design-broys.kicad_sch]
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2022-06-13 Added LED driving resistor.
    [watchular_hardware_design.kicad_pcb, watchular_hardware_design.kicad_sch]
2022-06-13 Added resistors for the LEDs but alrady running into the IO count problem.
    [watchular_hardware_design.kicad_sch]
2022-06-14 Configured boot strapping pins
    [watchular_hardware_design.kicad_pcb, watchular_hardware_design.kicad_sch]
2022-06-14 Added ceramic chip antenna to the project.
    [2450AT18A100E.step, watchular_hardware_design.kicad_pcb, watchular_hardware_design.kicad_sch]
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2022-06-15 Added antenna to the MCU
    [watchular_hardware_design.kicad_pcb, watchular_hardware_design.kicad_sch]
2022-06-15 Made analog filter for VDD3P3.
    [watchular_hardware_design.kicad_pcb, watchular_hardware_design.kicad_sch]
2022-06-15 Added connections for XTAL_32K_P and XTAL_32K_N
    [watchular_hardware_design.kicad_sch]
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2022-06-15 Added caps for 3.3V for VDD3P3_RTC
    [watchular_hardware_design.kicad_sch]
2022-06-15 XTAL left to be connected
    [watchular_hardware_design.kicad_sch]
2022-06-16 Finished the boiler plate for ESP32C3.
    [watchular_hardware_design.kicad_sch]
2022-06-16 Clean up the schematic.
    [ABM1116.000MHZ-B7GT.STEP, peripherals.kicad_sch, watchular_hardware_design.kicad_pcb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]
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2022-06-16 Wired up the USB-C
    [watchular_hardware_design.kicad_pcb, watchular_hardware_design.kicad_sch]
2022-06-17 Added and wired up the LDO. Boiler plate done.
    [MIC5524-3.3YMT-TZ.step, watchular_hardware_design.kicad_pcb, watchular_hardware_design.kicad_sch]
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2022-06-20 Added ESD protection to the USB.
    [SR05.step, watchular_hardware_design.kicad_pcb, watchular_hardware_design.kicad_sch]
2022-06-20 Added current limiting resistors and connected to MCU.
    [peripherals.kicad_sch, watchular_hardware_design.kicad_pcb, watchular_hardware_design.kicad_sch]
2022-06-21 Added components for 4 digits.
    [peripherals.kicad_sch, watchular_hardware_design.kicad_sch]
2022-06-22 Added MOSFET-BSS123 to the project.
    [BSS123.step, peripherals.kicad_sch, watchular_hardware_design.kicad_pcb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]
2022-06-22 Added MOSFET to all 4 digits.
    [peripherals.kicad_sch, watchular_hardware_design.kicad_pcb, watchular_hardware_design.kicad_sch]
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2022-06-29 Added a 16 position header.
    [TSW-116-07-H-S.step, peripherals.kicad_sch, watchular_hardware_design.kicad_pcb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]
2022-07-03 Added 15 position 2.45mm headers.
    [TSW-115-07-H-S.step, peripherals.kicad_sch, watchular_hardware_design.kicad_pcb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]
2022-07-03 Connected MCU pins to the brekout 15 pos header.
    [peripherals.kicad_sch, watchular_hardware_design.kicad_sch]
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2022-07-06 Added mosfet for controlling the power source.
    [DMG1013UW-7.step, peripherals.kicad_sch, watchular_hardware_design.kicad_pcb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]
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2022-07-06 Dual power wired up
    [peripherals.kicad_sch, watchular_hardware_design.kicad_pcb, watchular_hardware_design.kicad_sch]
2022-07-06 Added back the 16 pin headers.
    [peripherals.kicad_sch, watchular_hardware_design.kicad_pcb, watchular_hardware_design.kicad_sch]
2022-07-06 Schematic is done for now.
    [peripherals.kicad_sch, watchular_hardware_design.kicad_pcb, watchular_hardware_design.kicad_sch]
2022-07-07 Started exploring the PCB editor.
    [watchular_hardware_design.kicad_pcb]
2022-07-08 Set the board size to adafruit feather size.
    [watchular_hardware_design.kicad_pcb]
2022-07-10 Started work on the PCB
    [watchular_hardware_design.kicad_pcb]
2022-07-11 Need to make put components on both sides...
    [watchular_hardware_design.kicad_pcb]
2022-07-12 Added mouting holes and assigned footprints.
    [peripherals.kicad_sch, watchular_hardware_design.kicad_sch]
2022-07-13 Bottom side elements first arrangement.
    [peripherals.kicad_sch, watchular_hardware_design.kicad_pcb, watchular_hardware_design.kicad_sch]
2022-07-13 USB and antenna locked.
    [watchular_hardware_design.kicad_pcb]
2022-07-14 Locked the board size.
    [watchular_hardware_design.kicad_pcb]
2022-07-14 Poured the inner planes.
    [watchular_hardware_design.kicad_pcb]
2022-07-14 Imported a bit smaller buttons.
    [TL3305AF260QG.step, peripherals.kicad_sch, watchular_hardware_design.kicad_pcb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]
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2022-07-14 Made a small calculator for the LED positions.
    [watchular_hardware_design.kicad_pcb]
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2022-07-15 Front panel fixed.
    [watchular_hardware_design.kicad_pcb]
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2022-07-17 Added 3d for headers. Fixed all the errors.
    [watchular_hardware_design.kicad_pcb]
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2022-07-21 Removed the filtering circuit for the VDDA to save space.
    [peripherals.kicad_sch, watchular_hardware_design.kicad_pcb, watchular_hardware_design.kicad_sch]
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2022-07-22 No errors on the DRC.
    [watchular_hardware_design.kicad_pcb]
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2022-07-22 Fixed the USBC position.
    [watchular_hardware_design.kicad_pcb]
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2022-07-23 Shortening a lot of wires.
    [watchular_hardware_design.kicad_pcb]
2022-07-25 Resized back the board to the original size.
    [watchular_hardware_design.kicad_pcb]
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2022-07-26 Fixed the silk screen on the bottom.
    [watchular_hardware_design.kicad_pcb]
2022-07-26 Connected A to B USB pads. No errors or warnings.
    [watchular_hardware_design.kicad_pcb]
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2022-07-26 Added open hardwre logo. Ready for the order.
    [watchular_hardware_design.kicad_pcb]
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

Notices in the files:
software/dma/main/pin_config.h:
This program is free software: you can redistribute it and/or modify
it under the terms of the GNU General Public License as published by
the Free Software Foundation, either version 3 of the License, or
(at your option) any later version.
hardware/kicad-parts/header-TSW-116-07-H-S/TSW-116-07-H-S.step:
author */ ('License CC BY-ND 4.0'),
